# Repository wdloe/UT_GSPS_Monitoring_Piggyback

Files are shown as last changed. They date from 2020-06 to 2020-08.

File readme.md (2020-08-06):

# Introduction
This application is a product solution to monitor Inmarsat GSPS UT Signal Strength on any location over the Internet. Signal Strength data is obtained from RSSI data of the following GSPS UT. The RSSI data is obtained by AT command (AT+CSQ). 

The Signal Strength data will be transmitted over the Internet after being processed by a Single Board Computer. SBC will be obtaining the data with a serial communication between it and the GSPS UT.

This application could be used on any internet connection (such as Wi-Fi, Wired Connection, and GSM) since it is linked with a Virtual Private Network (VPN), provided by ZeroTier.

This product solution contains the Software, Hardware, and its container.

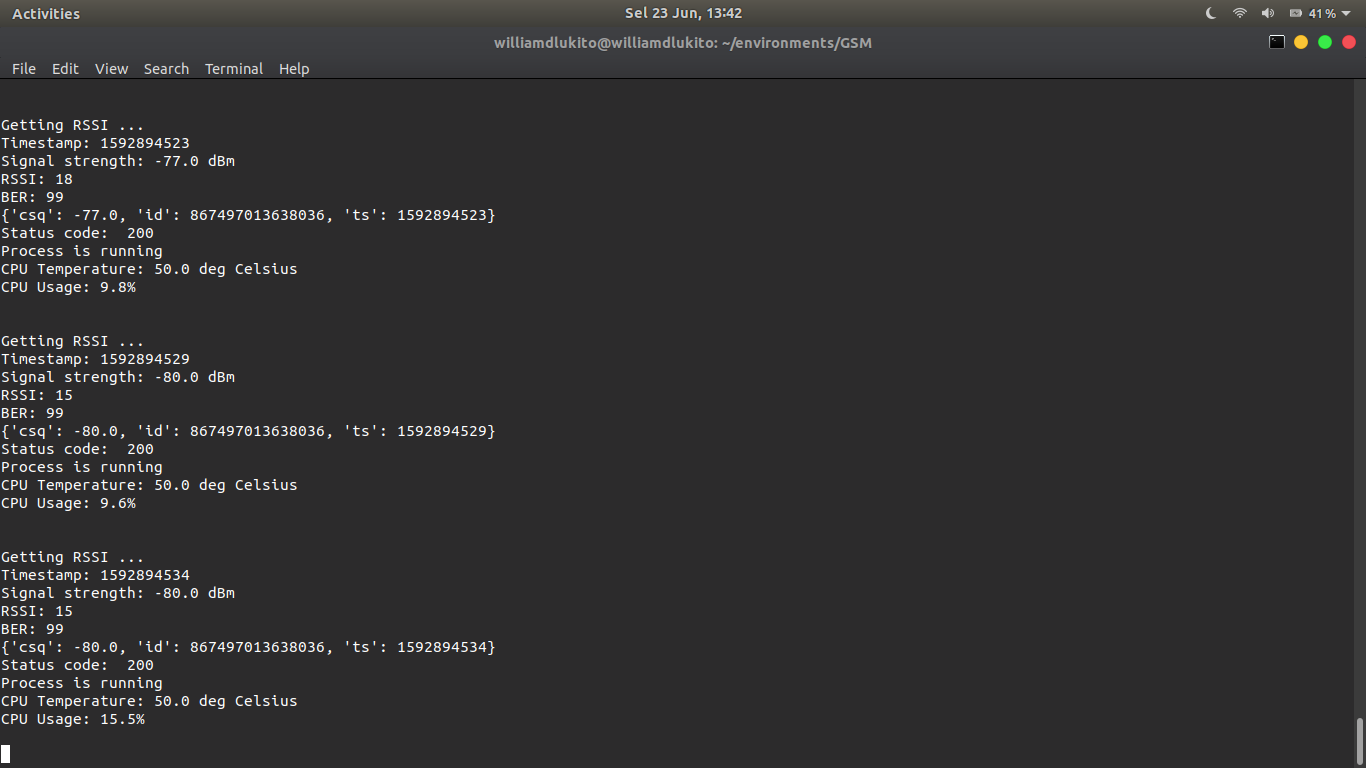
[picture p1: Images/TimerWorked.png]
Worked


# Requirements
1. Python 3
2. Linux Based OS
3. Libraries : serial, os, psutil, sys, time, requests, logging

# How to Use
## User Section
1.	Hardware is powered up by Power-over-Ethernet. So, just plug the RJ45 Cable (output of PoE adaptor) into PoE port in the side of the container.

2.	After the device is powered up, we could start to remote using SSH or Remote Desktop by connecting any Personal Computer (such as PCs, Laptops, Smartphones) to device’s public address. (Ask your Device administrator to know the IP address. The IP address is Static IPv4, so keep in mind.)

3.	Run the program by typing this following syntax on the Terminal/Serial Monitor.
~~~
bash launcher.sh &> /dev/null &
~~~

4.	The program should be run. If you want to close the process we could use two methods.
- By press Ctrl + C.
- Killing its PID, by type kill <PID> in another terminal. You can know the PID number by viewing last file created in the program directory.
  
## Admin Section
1.	For ease, we could configure the device by connecting the SBC to external peripheral, such as: monitor, keyboard, and mouse. Make sure the SBC is connected through the internet.

2.	Make sure that ZeroTier is installed on the SBC. After being installed, connect to our VPN. Contact your company to know the VPN ID. After knowing the VPN ID, input that ID to your ZeroTier interface to connect. Just wait for your company to approve your devices. The ZeroTier will be automatically run every boot. *(Note : Any method like NAT is no problem, since the admin and the remote SBC are in same network)*

3.	Once your device is being approved, you are already joined on our VPN. Run this syntax to know your network identity.
ifconfig
After knowing the public address, we could start to remote the SBC. Please keep in mind that local address is different with public address. In general, public address doesn’t start with 192.168.xxx.xxx.

4.	To run the program, make sure to have these 3 files.
-	launcher.sh
-	getRSSI.py
-	getRSSIevent.py

5. Run the program by typing this following syntax on the Terminal/Serial Monitor.
~~~
bash launcher.sh &> /dev/null &'
~~~

6. Once your program already ran, a new file should be appeared. That file is logging the PID number of the process. So, it is very helpful when we want to kill the process.

# How does the program work?
The program is working by using serial library. The serial library will make a communication to the GSPS UT. Since the GSPS UT has same base with GSM, we could use AT commands to it. Basically, the main program is just giving AT commands input in every period of time. The RSSI data is being collected by giving AT+CSQ command.

AT+CSQ command is giving this output: RSSI,BER. Since we are just going to obtain the RSSI, the program should slice it. For the device unique id, the program obtained IMEI data by giving AT+CGSN command.

Since the output of the serial is an array of character (string), the program should slice its output and translate from string to its adequate data type. By default, csq is float, id is integer, and ts is integer.
 
The program also could report the danger event. Such as: CPU overheat, CPU overload, process not running, and memory overload. 

# Container Specification
The container is fully designed by SolidWorks 2013. The dimensions of this container are 200x180x51 mm without lid, and 200x180x56 mm using lid. The container is using 3D print plastic material, and the lid is using acrylic with rubber around it. There is also passive humidity escape hole.

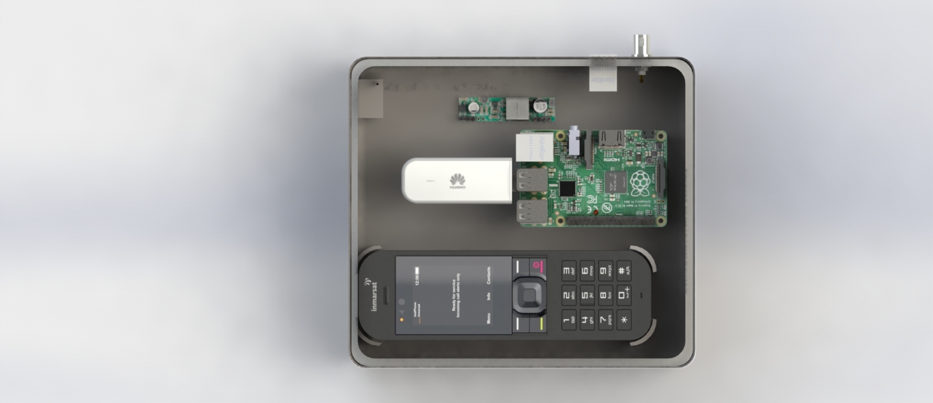
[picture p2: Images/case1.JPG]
ContainerA

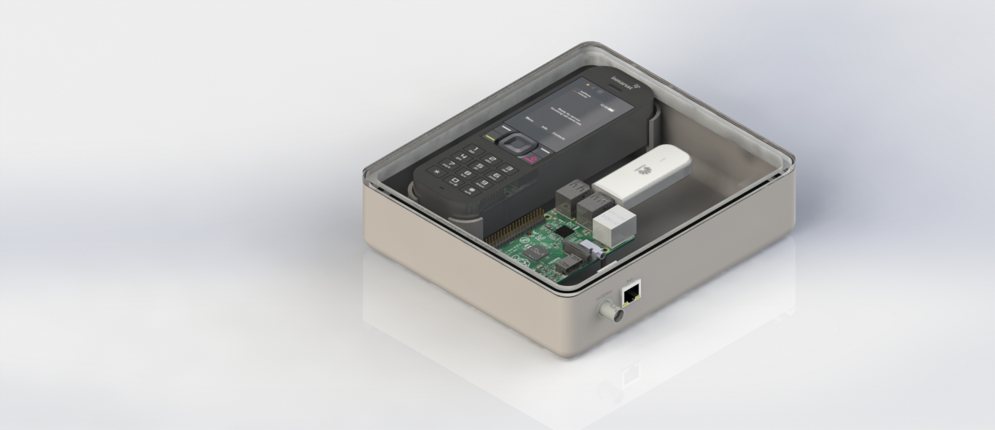
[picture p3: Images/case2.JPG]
ContainerB

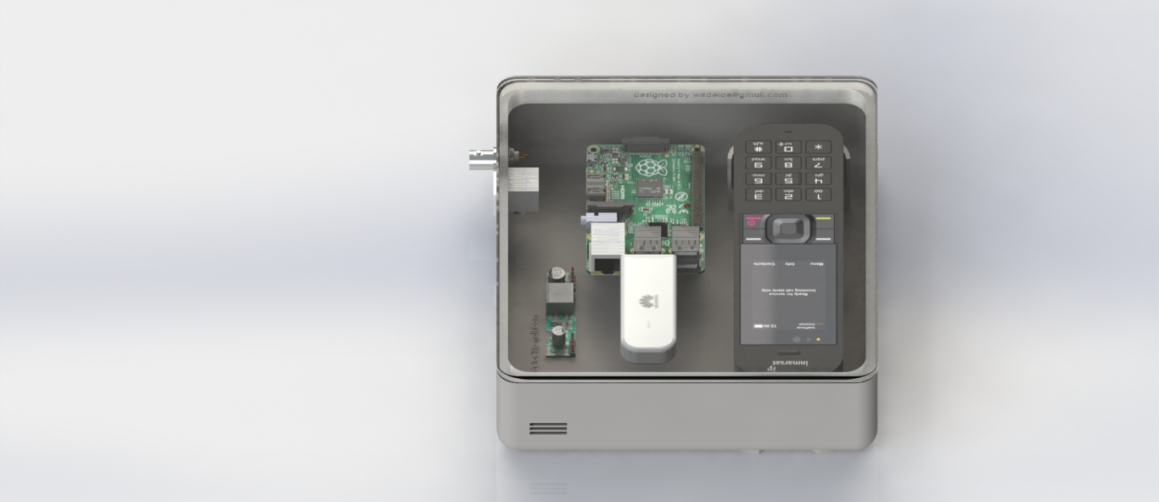
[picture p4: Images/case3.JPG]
ContainerC


To stick SBC to the container, use small screw and the using of rubber washer is recommended. IsatPhone2 is no need to use another screw since it has the following mounting at the bottom.

The container has two ports in the right side, there are: BNC connector for antenna and ethernet port for wired internet and PoE. The BNC connector is directly connected to L-band cable, which is ended up by connect it to the bottom of IsatPhone2. 

You can create a revision on my design by exploring the 'Casing' folder in this repository.

# Wiring Diagram
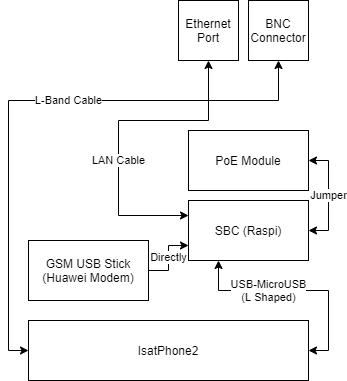
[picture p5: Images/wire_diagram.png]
Wiring Diagram


# Attachments
Remoting from Jakarta, Indonesia to the SBC in Batam, Indonesia. The result was so smooth.

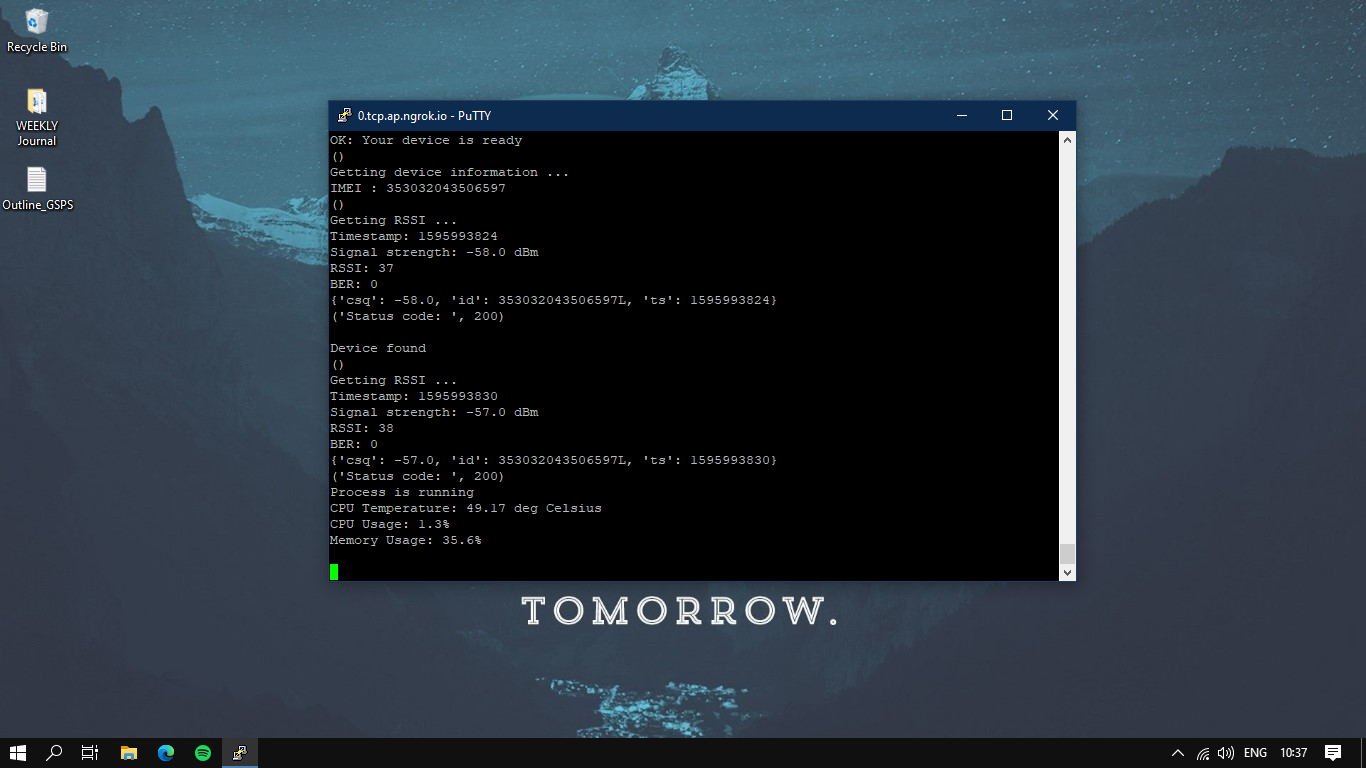
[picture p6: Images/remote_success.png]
RemoteMantap


Thank you for visiting this repository. Suggestions and advices are very welcome.
Feel free to contact me on 18117018@telecom.stei.itb.ac.id
WDL - 2020

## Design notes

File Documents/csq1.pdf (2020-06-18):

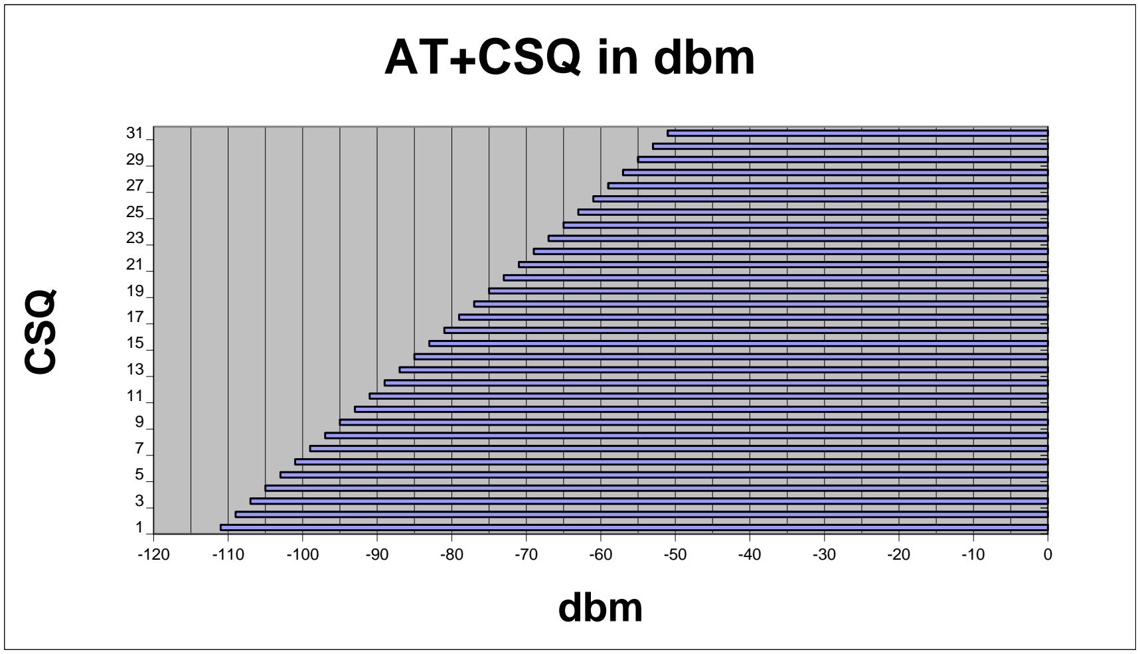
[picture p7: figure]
dbm; CSQ; AT+CSQ in dbm

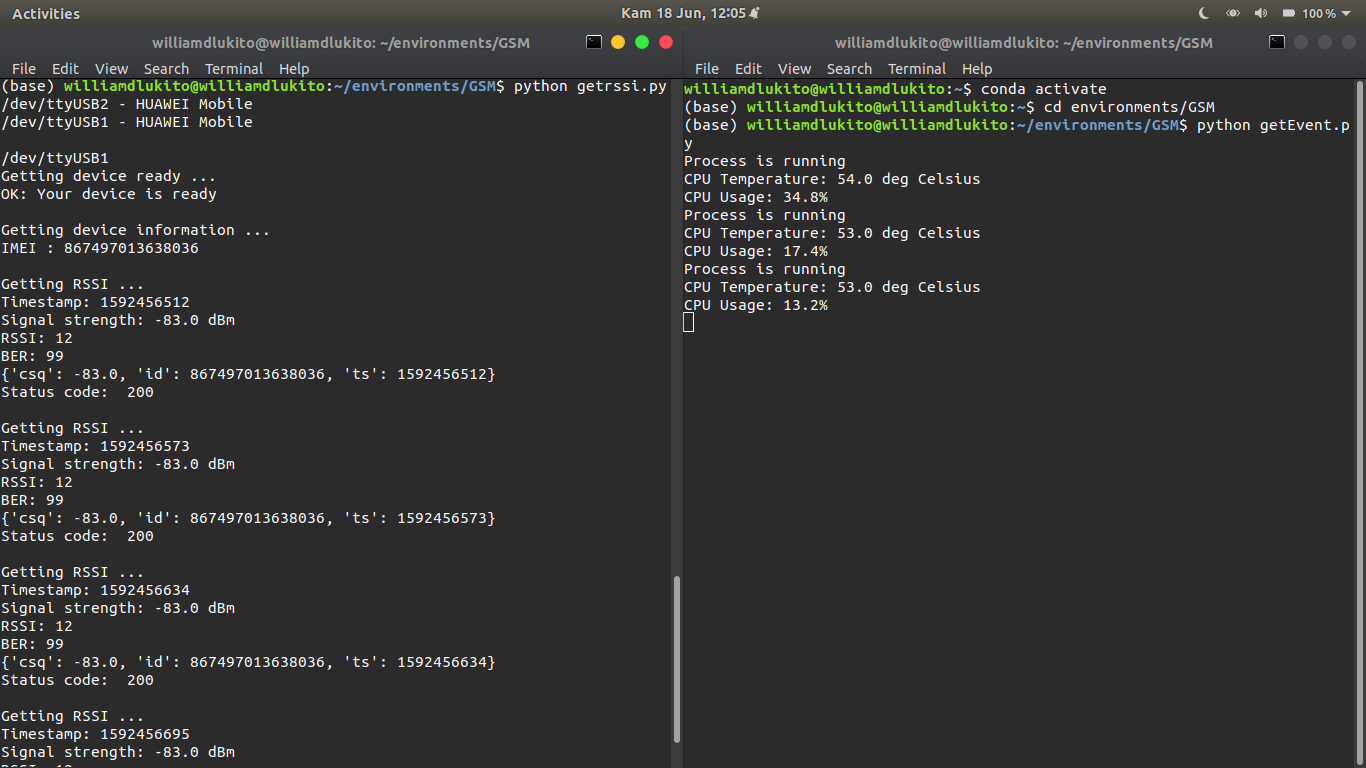
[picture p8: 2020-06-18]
Images/getRSSI&getEvent.png

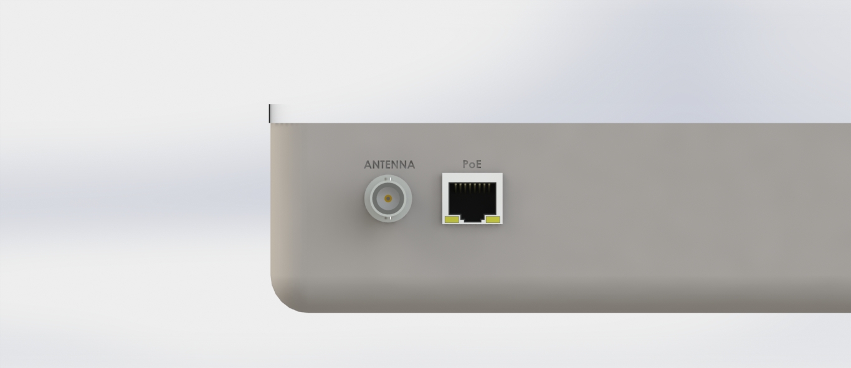
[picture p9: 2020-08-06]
Images/port_antena_poe.JPG

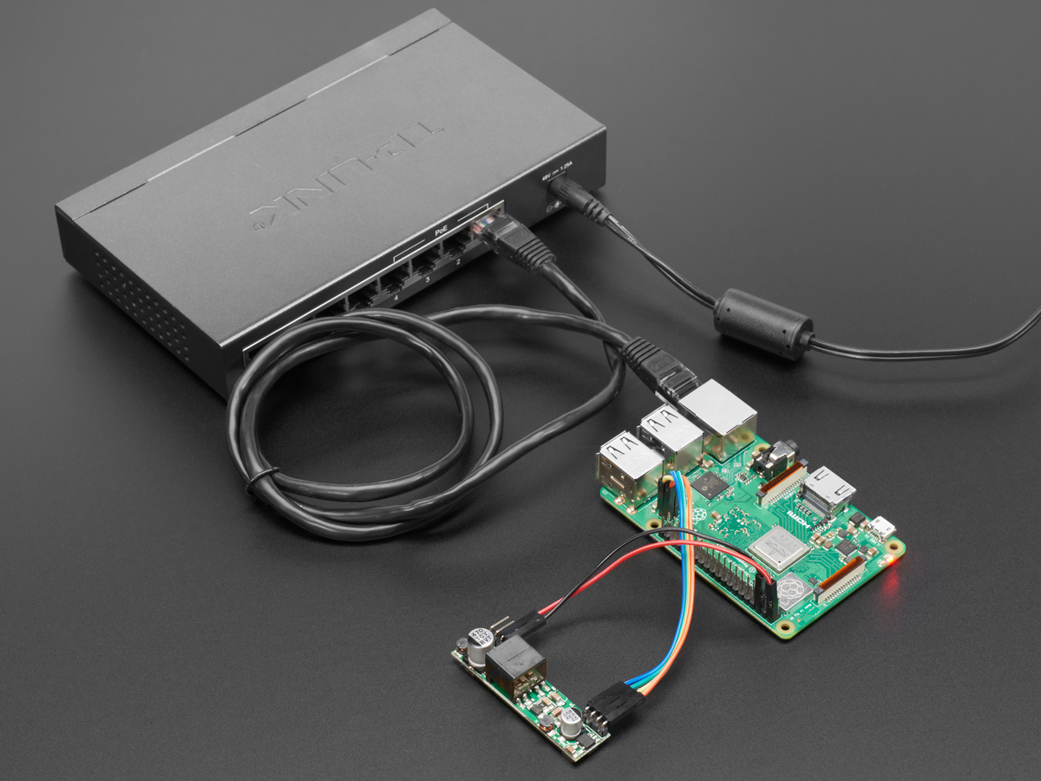
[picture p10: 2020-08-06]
Images/inspirePoE.jpg

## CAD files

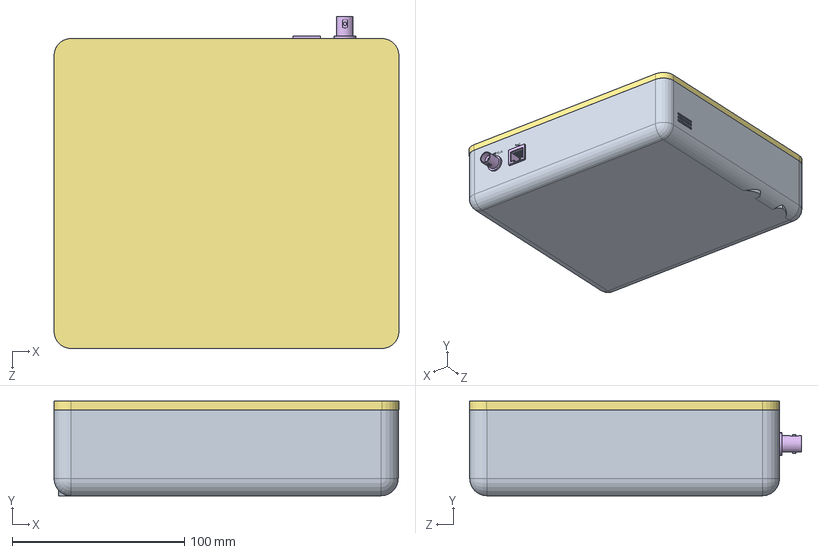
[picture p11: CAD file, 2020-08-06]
casing/Assem3_fan.SLDASM
200.4 x 55.0 x 193.0 mm
MainCont
isatphone2
raspberry_pi_B+_(bar_180_2x20)
raspberry_pi_B+_(QFN64)
raspberry_pi_B+_(168_FBGA_12x12)
raspberry_pi_B+_(USB_x2_part1) x 2
raspberry_pi_B+_(USB_x2_part2) x 2
raspberry_pi_B+_(micro_USB_cover)
raspberry_pi_B+_(micro_USB_contacts)
raspberry_pi__HDMI_socket_cover
raspberry_pi__HDMI_socket_inside
raspberry_pi__HDMI_socket_large_pin x 10
raspberry_pi__HDMI_socket_small_pin x 9
raspberry_pi_B+_(RJ45) x 2
raspberry_pi__15_pin_FFC_Connector_body x 2
raspberry_pi__15_pin_FFC_Connector_locker x 2
raspberry_pi__15_pin_FFC_Connector_pins x 30
raspberry_pi_B+_(CI_Board)
raspberry_pi_B+_(microsd_slot2)
raspberry_pi_B+_(microsd2)
raspberry_pi_B+_(audio_video2)
Разъем BNC NCB-0124, New Centress International (Тайвань)
Tutup
Huawei_E3531
blower_fan

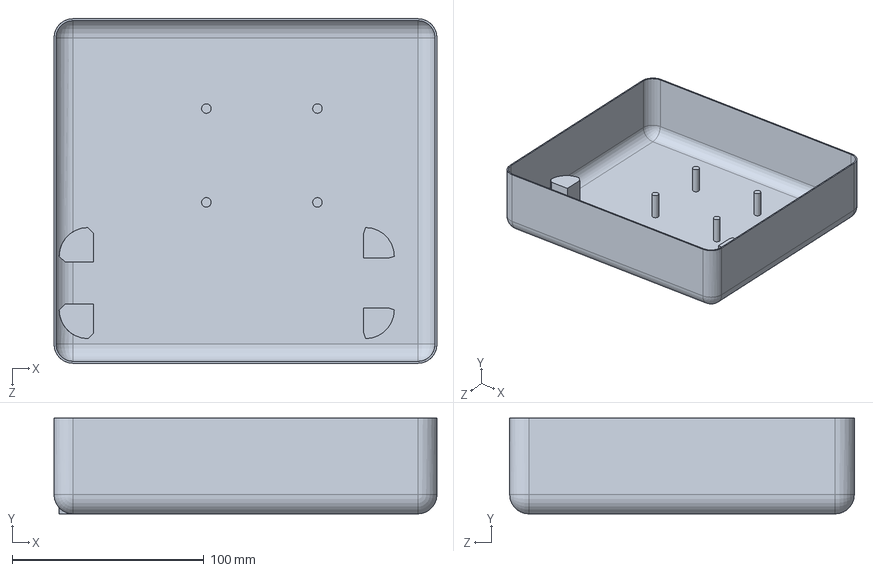
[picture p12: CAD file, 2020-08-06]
casing/MainCont.SLDPRT
200.0 x 50.0 x 180.0 mm

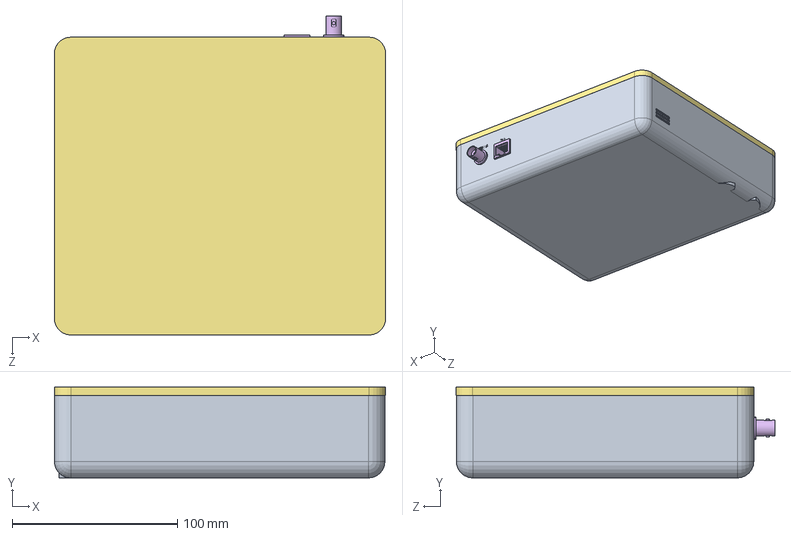
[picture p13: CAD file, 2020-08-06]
casing/Assem3.SLDASM
200.4 x 55.0 x 193.0 mm
MainCont
isatphone2
raspberry_pi_B+_(bar_180_2x20)
raspberry_pi_B+_(QFN64)
raspberry_pi_B+_(168_FBGA_12x12)
raspberry_pi_B+_(USB_x2_part1) x 2
raspberry_pi_B+_(USB_x2_part2) x 2
raspberry_pi_B+_(micro_USB_cover)
raspberry_pi_B+_(micro_USB_contacts)
raspberry_pi__HDMI_socket_cover
raspberry_pi__HDMI_socket_inside
raspberry_pi__HDMI_socket_large_pin x 10
raspberry_pi__HDMI_socket_small_pin x 9
raspberry_pi_B+_(RJ45) x 2
raspberry_pi__15_pin_FFC_Connector_body x 2
raspberry_pi__15_pin_FFC_Connector_locker x 2
raspberry_pi__15_pin_FFC_Connector_pins x 30
raspberry_pi_B+_(CI_Board)
raspberry_pi_B+_(microsd_slot2)
raspberry_pi_B+_(microsd2)
raspberry_pi_B+_(audio_video2)
Разъем BNC NCB-0124, New Centress International (Тайвань)
Tutup
Huawei_E3531
PoE_module

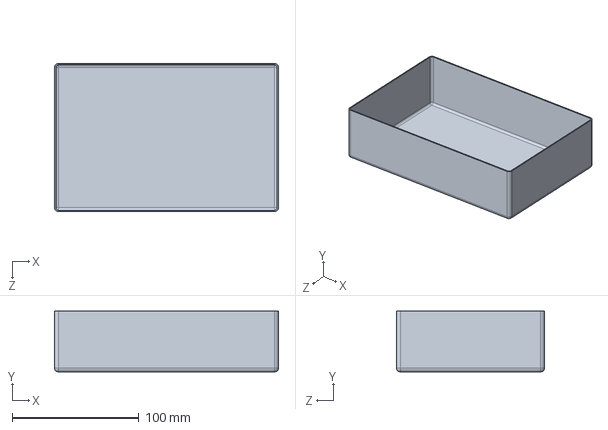
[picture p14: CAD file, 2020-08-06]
casing/Main.SLDPRT
177.0 x 48.0 x 117.0 mm

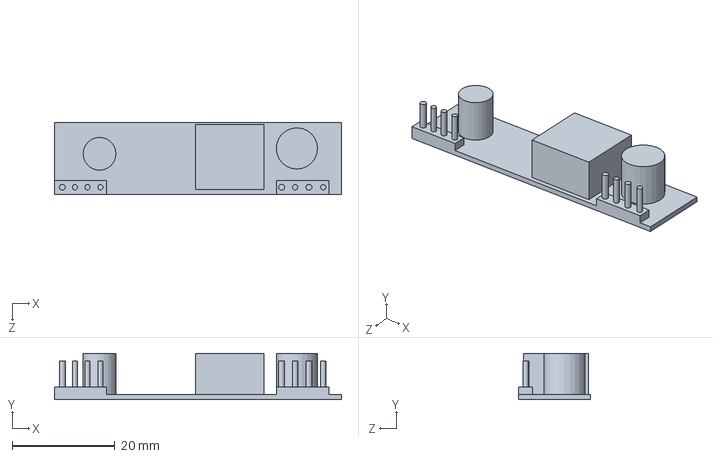
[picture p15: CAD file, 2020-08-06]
casing/PoE_module.SLDPRT
56.0 x 9.00 x 14.0 mm

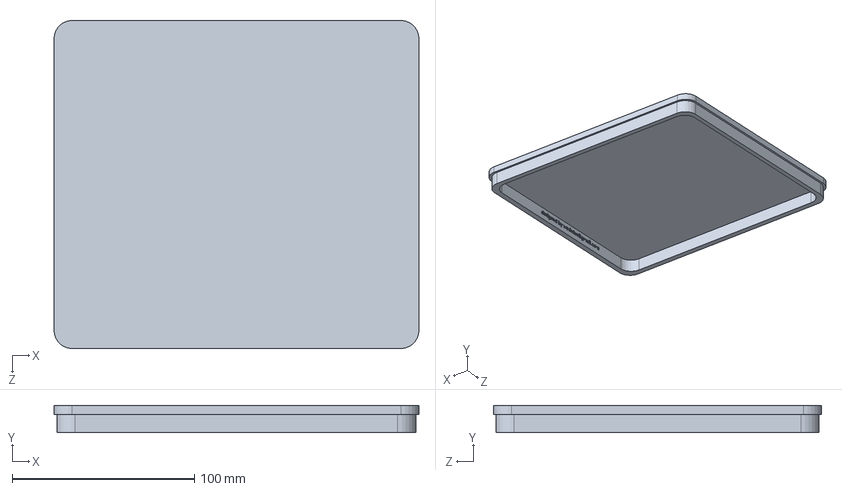
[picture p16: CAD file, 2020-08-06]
casing/Tutup.SLDPRT
200.4 x 15.0 x 180.2 mm

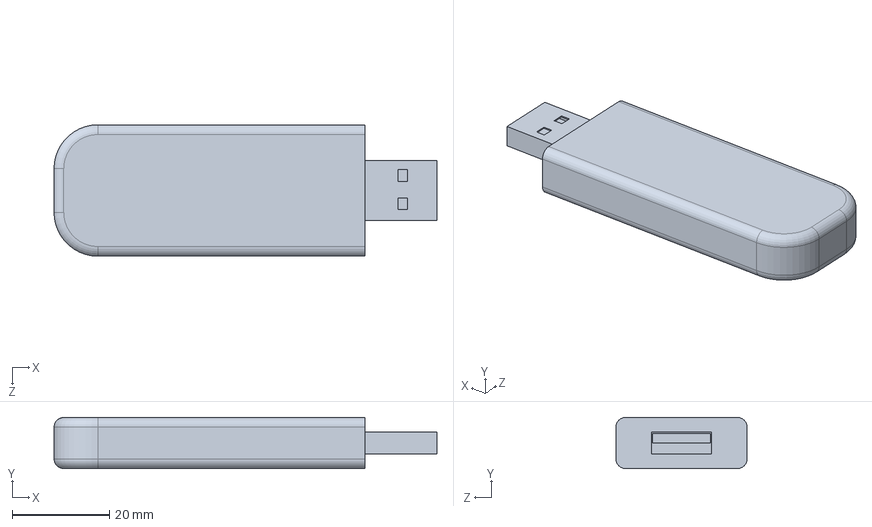
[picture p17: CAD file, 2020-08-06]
casing/Huawei_E3531.SLDPRT
78.7 x 10.5 x 27.0 mm

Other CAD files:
casing/Electrical_1-Assem3.sldasm

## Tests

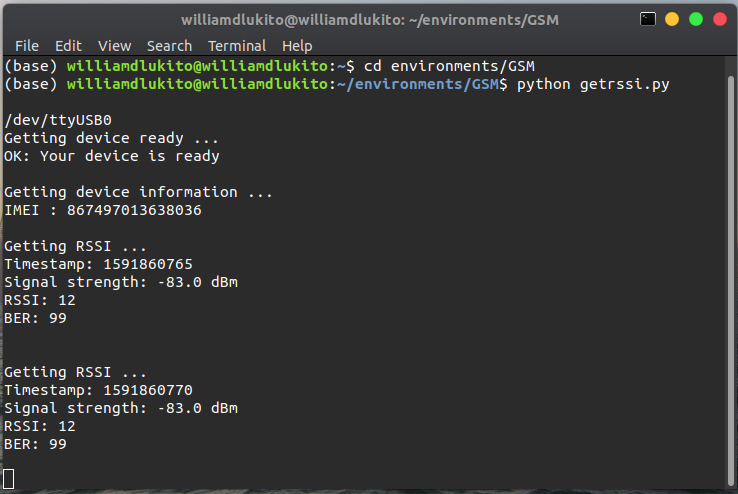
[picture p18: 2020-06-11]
Images/TerminalResult.jpg

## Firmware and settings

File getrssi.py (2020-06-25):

# GET RSSI DATA

import serial
import time
import requests

# autoconnect
import serial.tools.list_ports
ports = list(serial.tools.list_ports.comports())
for p in ports:
    print(p)
ut_port = p[0] #working perfectly on my Huawei Modem

#ut_port='/dev/ttyUSB0' #by default, in first after boot will be USB0
ut=serial.Serial(ut_port, 115200, timeout=2)
print()
print(ut.name)

#check OK
cmd_ok='AT\r'
ut.write(cmd_ok.encode())
print('Getting device ready ... ')

ut_ok=ut.readline() #blank
ut_ok=ut.readline() #OK
ut_ok=ut_ok.decode('utf-8')
oke=ut_ok[0:2]
if oke=='OK':
    print(oke+': Your device is ready')
else:
    print(oke+': Your device is not ready. Please try again')
    
#checking device IMEI
ut.reset_output_buffer()
cmd_imei='AT+CGSN\r'
ut.write(cmd_imei.encode())
print()
print('Getting device information ... ')

ut_cgsn=ut.readline() #blank
ut_cgsn=ut.readline() #IMEI
ut_cgsn=ut_cgsn.decode('utf-8')
imei=ut_cgsn[0:15] #unique id upload to server
imei=int(imei) #convert to integer as spec
print("IMEI : " + str(imei))

while True:
	#getting RSSI data
	ut.reset_output_buffer()
	cmd_csq='AT+CSQ\r'
	epoch=int(time.time())
	ut.write(cmd_csq.encode())
	print()
	print('Getting RSSI ... ')

	ut_csq=ut.readline() #blank
	ut_csq=ut.readline() #OK
	ut_csq=ut.readline() #blank
	ut_csq=ut.readline() #CSQ
	ut_csq=ut_csq.decode('utf-8')
		
	colon=ut_csq.find(',')
	rssi=ut_csq[colon-2:colon]
	ber=ut_csq[colon+1:colon+3]
	rssi=int(rssi)
	ber=int(ber)
	csq=float(rssi-95) #meraki formula dbm https://documentation.meraki.com/MR/Monitoring_and_Reporting/Location_Analytics
	print("Timestamp: " + str(epoch))
	print("Signal strength: " + str(csq) + " dBm")
	print("RSSI: " + str(rssi))
	print("BER: " + str(ber))
		
	json={"csq":csq,"id":imei,"ts": epoch}
	response = requests.post("https://vms.inmarsat.com/apiv2", json=json)
	print(json)
	print("Status code: ", response.status_code)
	time.sleep(5)
    

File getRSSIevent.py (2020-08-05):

#!/usr/bin/env python

# GET EVENT DATA

import os
import psutil
import sys
import time
import requests
import logging

logging.basicConfig(filename='log-file.log',level=logging.DEBUG)

#guidance
## Failure and event reporting of the device (process not running, processor overheat, lost
## connection to GSPS terminal, CPU more than 80% etc)
loop = True

while loop == True: #initate infinite loop every 60 seconds
	
	epoch = int(time.time()) # time on current loop
	
	# detecting connection to User Terminal
	usb_found = False
	while usb_found == False:
		import serial.tools.list_ports
		ports = list(serial.tools.list_ports.comports())
		if ports == []:
			print()
			print('Device not Found. Please check the connection.')
			print('Waiting 5 seconds ...')
			logging.debug('USB not found ' + str(epoch))
			usb_found = False
		else:
			print()
			print('Device found')
			usb_found = True
		
		time.sleep(5)

	# detecting process
	from subprocess import Popen

	found_process = False
	for process in psutil.process_iter():
		if process.cmdline() == ['python', 'getrssi.py']:
			#sys.exit('Process found: exiting.')
			found_process = True
			print("Process is running")

	if found_process == False:
		found_process = False
		response = requests.post("https://vms.inmarsat.com/apiv2", json={"event":"process not running","ts": epoch, "severity":0})
		print("Process Status code: ", response.status_code)
		logging.debug('Process not running ' + str(epoch))
		print('Process not found: starting it.')
		Popen(['python', 'getrssi.py'])
		
	# detecting processor overheat
	def get_cpu_temp():
		tempFile = open( "/sys/class/thermal/thermal_zone0/temp" )
		cpu_temp = tempFile.read()
		tempFile.close()
		return round(float(cpu_temp)/1000, 2)

	cpu_temp = get_cpu_temp()
	print("CPU Temperature: " + str(cpu_temp) + " deg Celsius")

	## deciding overheat or not
	### from several literature and documents said that raspi should be working normally below 80 deg celsius.
	overheat = False
	if cpu_temp > 70: # if cpu temp more than 80 deg celsius
		print('CPU Overheating ...')
		overheat = True
		response = requests.post("https://vms.inmarsat.com/apiv2", json={"event":"processor overheat","ts": epoch, "severity":1})
		print("Heat Status code: ", response.status_code)
		logging.debug('CPU overheat ' + str(epoch))
	else:
		#print('CPU is on Working temperature')
		overheat = False

	# detecting CPU overload
	overload = False
	cpu_usage = psutil.cpu_percent()
	print("CPU Usage: " + str(cpu_usage) + "%")

	if cpu_usage > 80: # if cpu usage more than 80 percent
		print('CPU Overload ... ')
		overload = True
		response = requests.post("https://vms.inmarsat.com/apiv2", json={"event":"processor overheat","ts": epoch, "severity":1})
		print("CPU Status code: ", response.status_code)
		logging.debug('CPU usage overload ' + str(epoch))
	else:
		#print('CPU is working normally')
		overload = False

	# detecting memory overload
	mem_overload = False
	memory_usage = psutil.virtual_memory().percent
	print("Memory Usage: " + str(memory_usage) + "%")

	if memory_usage > 80: # if cpu usage more than 80 percent
		print('Caution. High usage on memory ')
		mem_overload = True
		response = requests.post("https://vms.inmarsat.com/apiv2", json={"event":"processor overheat","ts": epoch, "severity":1})
		print("Memory Status code: ", response.status_code)
		logging.debug('Memory usage overload ' + str(epoch))
	else:
		#print('Memory is working normally')
		overload = False	
	
	print()	
	time.sleep(5)
